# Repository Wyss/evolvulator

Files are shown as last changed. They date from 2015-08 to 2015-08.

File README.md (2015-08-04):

## Evolvulator readme

Server dependencies include: Python 2.7, Twisted, autobahn.websocket, and Flask

### Bioreactor setup

1. Connect small quick release tube to the stop cock of the media reservoirs and attach with a zip tie.
2. Connect bioreactor feeder tube to fresh media reservoir.
3. Connect bioreactor waste tube to waste reservoir.
4. Connect equalizer tubing between waste and fresh media reservoirs.
5. Tape equalizer tubing to the side of media reservoir.
6. Tighten all ports on the top of bioreactor.
7. Fill bioreactor by opening media reservoir stop cock.
8. Once full place feeder tube into the pinch valve.
9. Check that feeder tubing is completely in the valve and make sure all connector tops on the top of the bioreactor are tight!

### Setting up the server:

Create a new database file:

1. navigate to `<repository_path>/code/service/experimentcore`
2. run python
3. type “from exp_dbifc import createDB” without quotes
4. type “createDB(“/location/of/created/database/file_name.DB”)” don't type outside-most quotes
a) replace /location/of/created/database/ with the path to the directory where the database will be created
b) replace file_name with the name of the database.
c) e.g. /home/wade/Documents/Evolvulator/database/Wade.DB

start the server with the following command:

    twistd -noy app.tac

To output information displayed in the terminal to a log file initiate the server with the following command:

    twistd -noy app.tac | tee logfile.txt or twistd -noy app.tac > logfile.txt

### Creating an experiment

Create a `*_evo.json` file for each Evolvulator hardware you would like to run in
`<repository_path>/code/service/evolvulator`

Use the evo_example_evo.json as a template

### Starting the server:

1. cd to `<repository_path>/code/service`

2. start server with `twistd -noy app.tac > date_log.txt`

3. open localhost:8080 in your preferred browser

4. open new tabs for Evo evo

### Running an experiment

1. After filling each bioreactor with clean media, turn on the stir bar, and change the max sensor reading (blank) on the control web page with the strip chart.  You can determine the max sensor reading by opening a web page of each Evolvulator IP and looking at Analog 2.  Refresh a couple times to get accurate reading.

2. On the control web page hit the “Start” button to begin recording data to database.  Hit “Loop” to start control loop.

3. After experiment is complete, copy and rename the Wade.DB files to save all data.

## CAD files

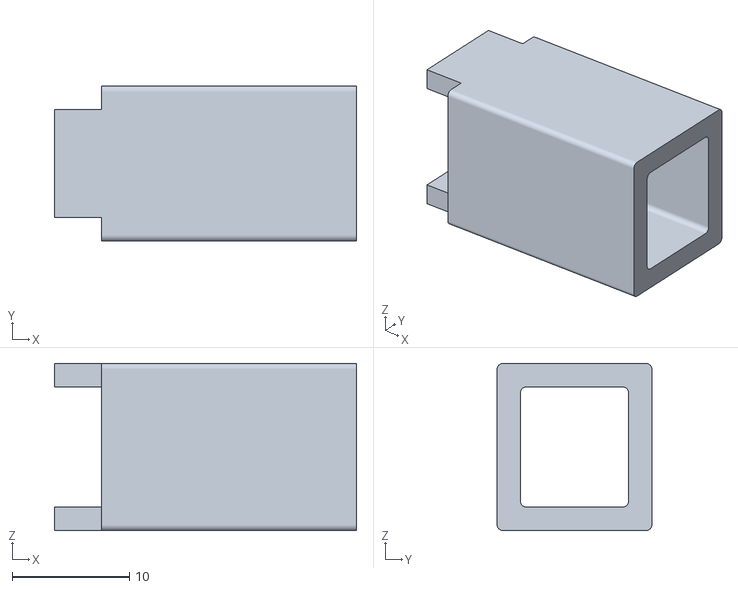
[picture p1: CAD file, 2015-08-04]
CAD/mechanical/shroud.STL
25.7 x 13.2 x 14.2

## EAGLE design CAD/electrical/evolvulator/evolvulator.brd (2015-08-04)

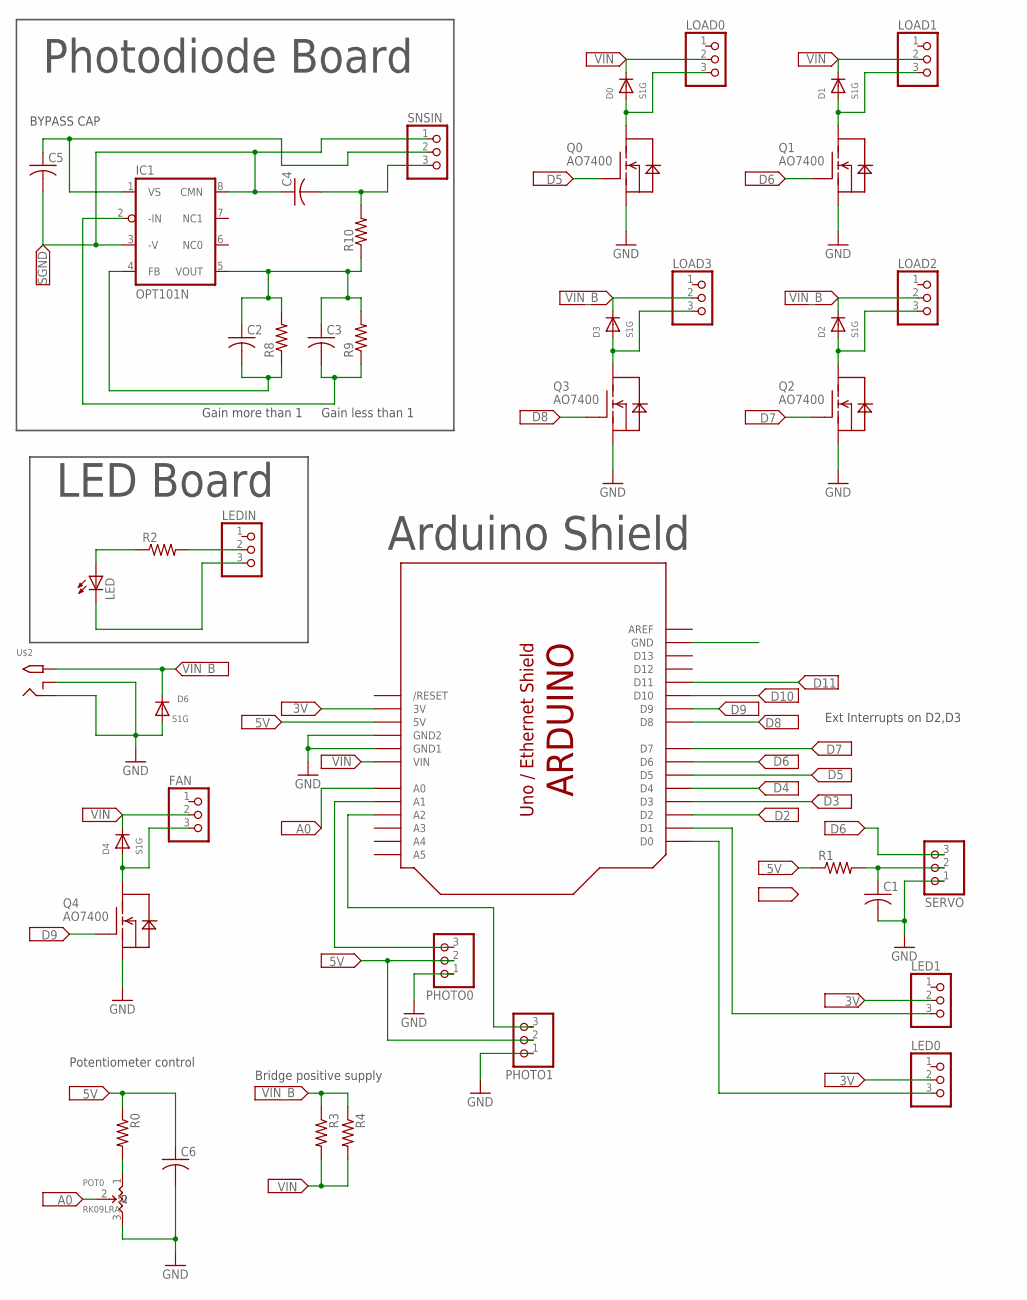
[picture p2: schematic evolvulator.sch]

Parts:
C1, C2, C3, C4, C5, C6: C_US; C0603
D0, D1, D2, D3, D4, D6: S1G; SMA_DIODE
FAN: PINHD-1X3; 1X03
IC1: OPT101N; DIL08-ROUND
LED: LED3MM
LED0, LED1: PINHD-1X3; 1X03
LEDIN: PINHD-1X3NB; 1X03_NB
LOAD0, LOAD1, LOAD2, LOAD3: PINHD-1X3; 1X03
PHOTO0, PHOTO1: PINHD-1X3; 1X03
POT0: RK09LRA; ALPS_POT_9MM_RA
Q0, Q1, Q2, Q3, Q4: AO7400; SOT23_FET
R0, R1, R2, R3, R4, R8, R9, R10: R_US; M0805
SERVO: PINHD-1X3; 1X03
SNSIN: PINHD-1X3NB; 1X03_NB
U$1: ARDUINOMAX; ARDUINOSHIELD-MAX
U$2: 2.1MMJACKTHM; PJ-102A

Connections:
3V: LED0.2, LED1.2, U$1.3V
5V: C6.1, PHOTO0.2, PHOTO1.2, R0.1, R1.1, U$1.5V
A0: POT0.2, U$1.A0
D2: U$1.D2
D3: U$1.D3
D4: U$1.D4
D5: Q0.G, U$1.D5
D6: Q1.G, SERVO.3, U$1.D6
D7: Q2.G, U$1.D7
D8: Q3.G, U$1.D8
D9: Q4.G, U$1.D9
D10: U$1.D10
D11: U$1.D11
D222: D3.A, LOAD3.3, Q3.D
GND: C1.2, C6.2, D6.A, PHOTO0.1, PHOTO1.1, POT0.3, Q0.S, Q1.S, Q2.S, Q3.S, Q4.S, SERVO.1, U$1.GND1, U$1.GND2, U$2.RING, U$2.RING_SW
unnamed: C1.1, R1.2, SERVO.2
unnamed: PHOTO0.3, U$1.A1
unnamed: LED1.3, U$1.D1
unnamed: D4.A, FAN.3, Q4.D
unnamed: LED0.3, U$1.D0
unnamed: POT0.1, R0.2
unnamed: C3.2, IC1.2 (-IN), R9.1
unnamed: LEDIN.2, R2.2
unnamed: C2.1, C3.1, IC1.5 (VOUT), R8.2, R9.2, R10.1
unnamed: C2.2, IC1.4 (FB), R8.1
unnamed: C5.1, IC1.1 (VS), SNSIN.2
unnamed: LED.A, R2.1
unnamed: LED.K (C), LEDIN.3
unnamed: PHOTO1.3, U$1.A2
unnamed: C4.2, R10.2, SNSIN.3
unnamed: D0.A, LOAD0.3, Q0.D
unnamed: D1.A, LOAD1.3, Q1.D
unnamed: D2.A, LOAD2.3, Q2.D
SGND: C4.1, C5.2, IC1.3 (-V), IC1.8 (CMN), SNSIN.1
VIN: D0.C, D1.C, D4.C, FAN.2, LOAD0.2, LOAD1.2, R3.2, R4.2, U$1.VIN
VIN_B: D2.C, D3.C, D6.C, LOAD2.2, LOAD3.2, R3.1, R4.1, U$2.TIP

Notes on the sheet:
BYPASS CAP
Gain less than 1
Gain more than 1
Photodiode Board
LED Board
Arduino Shield
Ext Interrupts on D2,D3
Bridge positive supply
Potentiometer control

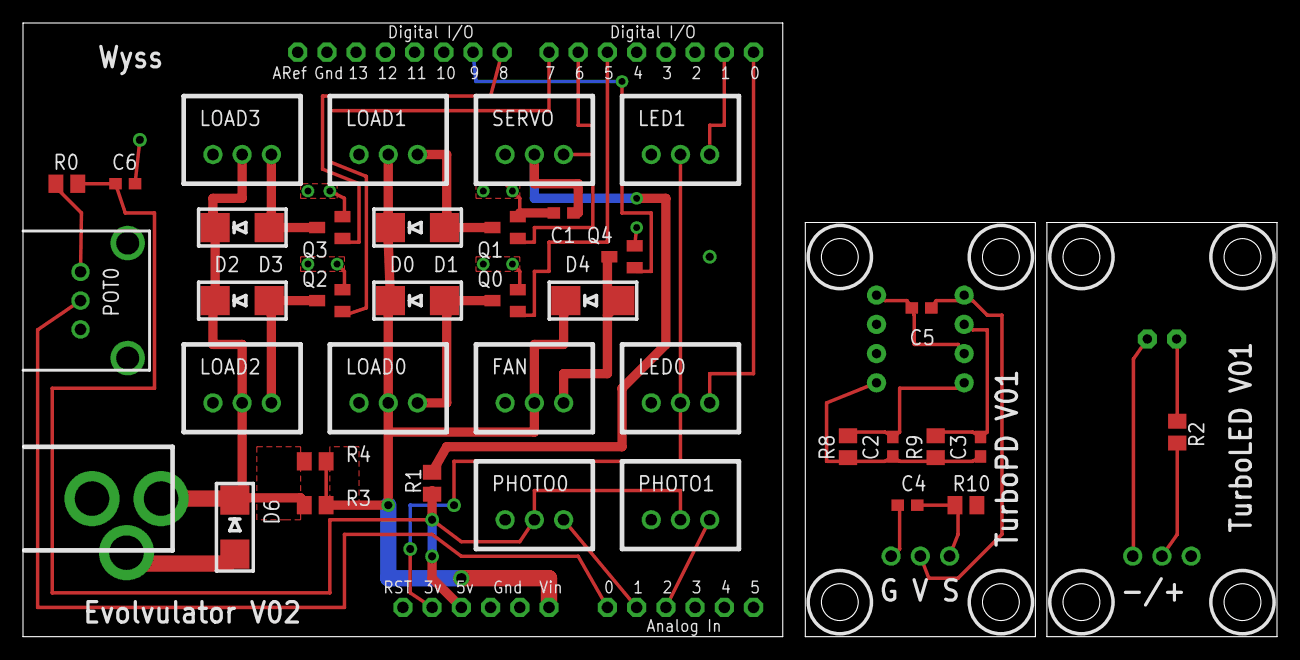
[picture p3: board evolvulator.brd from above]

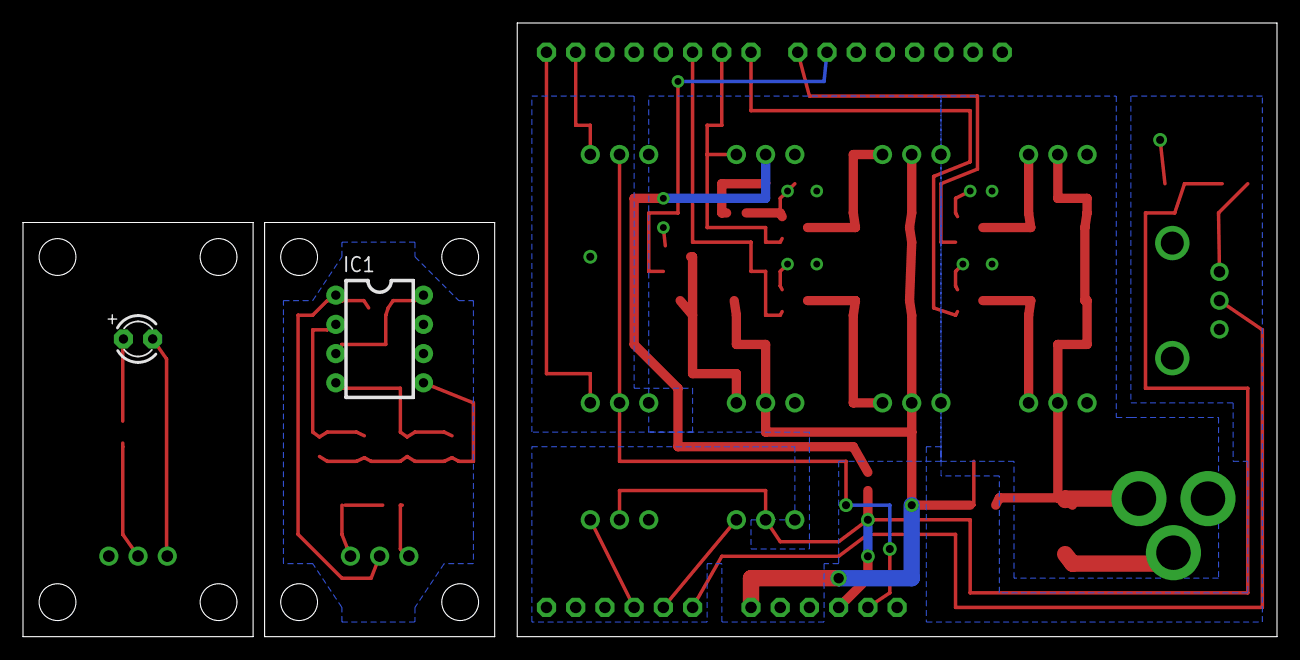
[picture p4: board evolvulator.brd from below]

Board: 2 copper layers, 109.0 x 53.3 mm, 42 parts (3 on the bottom side), 31 nets.

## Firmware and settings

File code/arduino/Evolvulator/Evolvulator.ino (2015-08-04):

// Copyright (c) 2011 Wyss Institute at Harvard University
// 
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
// http://www.opensource.org/licenses/mit-license.php



// Evolvulator.ino -- derived from Web_Demo.ino sample code for Webduino server 
//                      library
// dependency Webduino webserver library
// https://github.com/sirleech/Webduino
 
// http://host/
// This URL brings up a display of the values READ on digital pins 0-9
// and analog pins 0-5.  This is done with a call to defaultCmd.
//
// http://host/form
// This URL also brings up a display of the values READ on digital pins 0-9
// and analog pins 0-5.  But it's done as a form,  by the "formCmd" function,
// and the digital pins are shown as radio buttons you can change.
// When you click the "Submit" button,  it does a POST that sets the
// digital pins,  re-reads them,  and re-displays the form.
//
// http://host/json
// return: response JSON formatted system state with respect to arduino pins
// 
// http://host/control
// input: GET request to turn on a LOAD
// return: response JSON formatted system state
//
// http://host/measurement
// input: none
// return: response JSON formatted system state


#define SERVER_IP 192,168,1,130
#define MAC_ADDRESS  0x40, 0xA2, 0xDA, 0x00, 0x75, 0xC3

#define PREFIX ""
#define NAMELEN 32
#define VALUELEN 32

//to prevent compiling errors in Ubuntu and Windows Arduino IDE, favicon should be defined in WebServer.h.

// Analog Pins
#define POTENTIOMETER_PIN 0
#define PHOTODIODE0_PIN 1
#define PHOTODIODE1_PIN 2
	 
// Digital Pins
#define FAN_PIN	9
#define LED0_PIN 0
#define LED1_PIN 1
#define LOAD0_PIN 5
#define LOAD1_PIN 6
#define LOAD2_PIN 7
#define LOAD3_PIN 8
#define _ON  1
#define _OFF 0

#include "SPI.h"
#include "avr/pgmspace.h" // new include
#include <string.h>
#include "Ethernet.h"
#include "WebServer.h"
#define VERSION_STRING "0.1"

// no-cost stream operator as described at 
// http://sundial.org/arduino/?page_id=119
template<class T>
inline Print &operator <<(Print &obj, T arg) { obj.print(arg); return obj; }

// CHANGE THIS TO YOUR OWN UNIQUE VALUE
static uint8_t mac[] = {  MAC_ADDRESS };

// CHANGE THIS TO MATCH YOUR HOST NETWORK
static uint8_t ip[] = {SERVER_IP}; 

WebServer webserver(PREFIX, 80);

//
uint16_t potentiometer_value = 0;
uint16_t photodiode0_value = 0;
uint16_t photodiode1_value = 0;
uint8_t fan_status = _ON;
void load_on(uint8_t load_pin);
void load_off(uint8_t load_pin);

// commands are functions that get called by the webserver framework
// they can read any posted data from client, and they output to server

void isLOADOn(WebServer &server, WebServer::ConnectionType type, uint8_t pin) 
{
    if (digitalRead(pin) == _ON) {
        server << "\"ON\"";
    }
    else {
        server << "\"OFF\"";
    }
}

void isLEDOn(WebServer &server, WebServer::ConnectionType type, uint8_t pin) 
{
    if (digitalRead(pin) == LOW) {
        server << "\"ON\"";
    }
    else {
        server << "\"OFF\"";
    }  
}

void returnState(WebServer &server, WebServer::ConnectionType type) 
{
    // return system state.  
    server << "{ ";
    server << "\"POTVALUE\": " << potentiometer_value;
    server << ", \"PHOTODIODE0\": " << photodiode0_value;
    server << ", \"PHOTODIODE1\": " << photodiode1_value;
    server << ", \"LOAD0\": "; isLOADOn(server, type, LOAD0_PIN);
    server << ", \"LOAD1\": "; isLOADOn(server, type, LOAD1_PIN);
    server << ", \"LOAD2\": "; isLOADOn(server, type, LOAD2_PIN);
    server << ", \"LOAD3\": "; isLOADOn(server, type, LOAD3_PIN);
    server << ", \"LED0\": "; isLEDOn(server, type, LED0_PIN);
    server << ", \"LED1\": "; isLEDOn(server, type, LED1_PIN);
    server << " }";
}

void measurementCmd(WebServer &server, WebServer::ConnectionType type, char *url_tail, bool tail_complete)
{
    if (type == WebServer::POST) {
        server.httpFail();
        return;
    }

    server.httpSuccess("application/json");
    
    if (type == WebServer::HEAD) {
        return;
    }
    returnState(server,type);
}

void controlCmd(WebServer &server, WebServer::ConnectionType type, char *url_tail, bool tail_complete)
{
    URLPARAM_RESULT rc;
    char name[NAMELEN];
    int  name_len;
    char value[VALUELEN];
    int value_len;
    int loadnum;

    /* this line sends the standard "we're all OK" headers back to the
       browser */
    server.httpSuccess("application/json");

    /* if we're handling a GET or POST, we can output our data here.
       For a HEAD request, we just stop after outputting headers. */
    if (type == WebServer::HEAD) {
        return;
    }

    if (strlen(url_tail)) {
        while (strlen(url_tail)) {
            rc = server.nextURLparam(&url_tail, name, NAMELEN, value, VALUELEN);
            if (rc == URLPARAM_EOS) {
            }
            else {
                if (strncmp(name, "LOAD", 4) == 0) {
                    loadnum = abs(name[4] - '0');
                    // for now, let's turn the fan on and off
                    if (loadnum < 4) {
                        if (strncmp(value, "ON", 2) == 0) {
                            load_on(loadnum);
                        }
                        else {
                            load_off(loadnum);
                        }
                    } // end if
                } // end if strncmp
            } // end  else
        } // end while
    } // end if
    returnState(server,type);
}

// from Web_Demo.ino 
void jsonCmd(WebServer &server, WebServer::ConnectionType type, char *url_tail, bool tail_complete) {
    if (type == WebServer::POST) {
        server.httpFail();
        return;
    }

    server.httpSuccess("application/json");

    if (type == WebServer::HEAD)
        return;

    int i;    
    server << "{ ";
    for (i = 0; i <= 9; ++i) {
        // ignore the pins we use to talk to the Ethernet chip
        int val = digitalRead(i);
        server << "\"d" << i << "\": " << val << ", ";
    }

    for (i = 0; i <= 5; ++i) {
        int val = analogRead(i);
        server << "\"a" << i << "\": " << val;
        if (i != 5) { 
            server << ", ";
        }
    }
  
    server << " }";
}

// from Web_Demo.ino for debugging use only 
void outputPins(WebServer &server, WebServer::ConnectionType type, bool addControls = false)
{
    P(html_head) =
    "<html>"
    "<head>"
    "<title>Evolvulator Web Server</title>"
    "<style type=\"text/css\">"
    "BODY { font-family: sans-serif }"
    "H1 { font-size: 14pt; text-decoration: underline }"
    "P  { font-size: 10pt; }"
    "</style>"
    "</head>"
    "<body>";
    P(digital_pin_header) = "<h1>Digital Pins</h1><p>";
    P(analog_pin_header) = "</p><h1>Analog Pins</h1><p>";
    
    int i;
    server.httpSuccess();
    server.printP(html_head);

    if (addControls) {
        server << "<form action='" PREFIX "/form' method='post'>";
    }

    server.printP(digital_pin_header);

    for (i = 0; i <= 9; ++i) {
        // ignore the pins we use to talk to the Ethernet chip
        int val = digitalRead(i);
        server << "Digital " << i << ": ";
        if (addControls) {
            char pin_name[4];
            pin_name[0] = 'd';
            itoa(i, pin_name + 1, 10);
            server.radioButton(pin_name, "1", "On", val);
            server << " ";
            server.radioButton(pin_name, "0", "Off", !val);
        }
        else {
            server << (val ? "HIGH" : "LOW");
        }
        server << "<br/>";
    }

    server.printP(analog_pin_header);
    
    for (i = 0; i <= 5; ++i) {
        int val = analogRead(i);
        server << "Analog " << i << ": " << val << "<br/>";
    }

    server << "</p>";

    if (addControls) {
        server << "<input type='submit' value='Submit'/></form>";
    }
    server << "</body></html>";
}

// from Web_Demo.ino for debugging use only 
void formCmd(WebServer &server, WebServer::ConnectionType type, char *url_tail, bool tail_complete) 
{
    if (type == WebServer::POST) {
        bool repeat;
        char name[16], value[16];
        do {
            repeat = server.readPOSTparam(name, 16, value, 16);
            if (name[0] == 'd') {
                int pin = strtoul(name + 1, NULL, 10);
                int val = strtoul(value, NULL, 10);
                digitalWrite(pin, val);
            }
        } while (repeat);
        server.httpSeeOther(PREFIX "/form");
    }
    else {
        outputPins(server, type, true);
    }
}

// from Web_Demo.ino for debugging use only 
void defaultCmd(WebServer &server, WebServer::ConnectionType type, char *url_tail, bool tail_complete)
{
    outputPins(server, type, false);  
}


int checkFan(uint16_t *val_last)
// check status of the fan and update the speed
{
    uint16_t val = analogRead(POTENTIOMETER_PIN);
    // gotta drop 2 bits because 10 bit ADC, 8 bit PWM
    *val_last = (val + 3*(*val_last)) >> 2;     // weighted average value
    if (fan_status == _ON) {
        analogWrite(FAN_PIN, (*val_last) >> 3); // divide by 8 for a gain on the input
    }
    else {
        analogWrite(FAN_PIN, 0);
    }
    return 0;
}

void led_on(uint8_t led_pin)
{
    // LEDs are pull down
    digitalWrite(led_pin, LOW);
}

void led_off(uint8_t led_pin)
{
    // LEDs are pull down
    digitalWrite(led_pin, HIGH);
}

void load_on(uint8_t load_number)
{
    // assumes LOADX_PIN are sequential output pins on the arduino
    digitalWrite(LOAD0_PIN + load_number, HIGH);
}

void load_off(uint8_t load_number)
{
    // assumes LOADX_PIN are sequential output pins on the arduino
    digitalWrite(LOAD0_PIN +  load_number, LOW);
}

void checkPhotoDiode(uint16_t *val_last, uint8_t photodiode_pin, uint8_t led_pin)
{
    // Take the difference of the signal with the LED on, then the LED off
    // this takes care of the ambiant light bias
    
    led_on(led_pin);
    uint16_t val = (uint16_t) analogRead(photodiode_pin);
//    led_off(led_pin);
//    val -= analogRead(photodiode_pin);
    *val_last = (val + 3*(*val_last)) >> 2;
}

void setup()
{
    // set pins for digital output
    pinMode(LED0_PIN, OUTPUT);
    pinMode(LED1_PIN, OUTPUT);
    pinMode(FAN_PIN, OUTPUT);
    pinMode(LOAD0_PIN, OUTPUT);
    pinMode(LOAD1_PIN, OUTPUT);
    pinMode(LOAD2_PIN, OUTPUT);
    pinMode(LOAD3_PIN, OUTPUT);

    Ethernet.begin(mac, ip);
    webserver.begin();

    webserver.setDefaultCommand(&defaultCmd);
    webserver.addCommand("json", &jsonCmd);
    webserver.addCommand("control", &controlCmd);
    webserver.addCommand("measurement", &measurementCmd);
    webserver.addCommand("form", &formCmd);
}

void loop()
{
    // process incoming connections one at a time forever
    webserver.processConnection();
    
    // if you wanted to do other work based on a connecton, it would go here
    checkFan(&potentiometer_value);
    checkPhotoDiode(&photodiode0_value, PHOTODIODE0_PIN, LED0_PIN);
    checkPhotoDiode(&photodiode1_value, PHOTODIODE1_PIN, LED1_PIN);
}

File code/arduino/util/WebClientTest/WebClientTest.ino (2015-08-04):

/*
Copyright (c) 2011 Wyss Institute at Harvard University

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
http://www.opensource.org/licenses/mit-license.php

WebClientTest.ino - Arduino Web client For Evolvulator

This sketch connects to a webserver with a GET request
and uses the webservers response to set local variables. 

Originally designed for a client based deployment, it is now most useful
for logging a DHCP ip address for the arduino
 
Ethernet shield attached to pins 10, 11, 12, 13
*/

#include <SPI.h>
#include <Ethernet.h>

#define SERVER_IP 10,11,32,65
#define SERVER_PORT 8080


// Enter a MAC address for your controller below.
// Newer Ethernet shields have a MAC address printed on a sticker on the shield
//byte mac[] = {  0x90, 0xA2, 0xDA, 0x00, 0x75, 0xCC };
byte mac[] = {  0x90, 0xA2, 0xDA, 0x00, 0x75, 0xCD };
IPAddress server(SERVER_IP);

boolean headerDone = false;
boolean isHTTP = false;

String current_line = "";
int line_no = -1; // initialize to -1

// Initialize the Ethernet client library
// with the IP address and port of the server 
// that you want to connect to (port 80 is default for HTTP):
EthernetClient client;


// Functional prototypes
boolean isLineEnd(char c);
boolean isHeaderDone(String * line);
boolean isHeaderHTTP(String * line, int line_no);

void setup() 
{
    // start the serial library:
    Serial.begin(9600);
    // start the Ethernet connection:
    if (Ethernet.begin(mac) == 0) 
    {
        Serial.println("Failed to configure Ethernet using DHCP");
        // no point in carrying on, so do nothing forevermore:
        for(;;)
            ;
    }
    // give the Ethernet shield a second to initialize:
    delay(1000);
    Serial.println("connecting...");

    // if you get a connection, report back via serial:
    if (client.connect(server, SERVER_PORT)) 
    {
        Serial.println("connected");
        // Make a HTTP request:
        client.println("GET /foo?clientName=arduino_is_cool HTTP/1.0");
        //client.println("GET /search?q=arduino HTTP/1.0");
        client.println();
    } 
    else 
    {
        // kf you didn't get a connection to the server:
        Serial.println("connection failed, ah nuts");
    }
}

void loop()
{
    // if there are incoming bytes available 
    // from the server, read them and print them:
    boolean is_line_end;
    if (client.available()) 
    {
        // an http header ends with a blank line
        //boolean currentLineIsBlank = true;
        char c = client.read();
        current_line += c;
        
        if (is_line_end = isLineEnd(c)) 
        { 
            line_no += 1;
            if (!isHTTP)
            {
                if (isHeaderHTTP(&current_line, line_no))
                {
                    isHTTP = true;
                }
                else
                {
                    Serial.println("EPic FAIL");
                }
            }
        }
        
        if (headerDone)                     // print if body of response
        {
            Serial.print(c);
        }
        else if (is_line_end && isHeaderDone(&current_line)) // otherwise see if the header is done
        {
            headerDone = true;
        }
        
        // Now clear the line post everything else
        if (is_line_end) { current_line = ""; }
    }

    // if the server's disconnected, stop the client:
    if (!client.connected()) 
    {
        Serial.println();
        Serial.println("disconnecting.");
        headerDone = false;
        client.stop();
        // do nothing forevermore:
        for(;;)
            ;
    }
}

boolean isLineEnd(char c){
    return true ? c == '\n' : false;
}

boolean isHeaderDone(String * line){
    return true ? line->startsWith("\r\n") : false;
}

boolean isHeaderHTTP(String * line, int line_no)
{
    if (line_no  == 0)
    {
        return true ? line->startsWith("HTTP") : false; 
    }
    else
    {
        return false;
    } 
}
